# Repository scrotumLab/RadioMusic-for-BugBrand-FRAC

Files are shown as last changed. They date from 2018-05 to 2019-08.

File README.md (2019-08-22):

# RadioMusic v3.2 for BugBrand Modular System
With the permission of Tom Whitwell (Music Thing Modular), creator of [the original Radio Music module](https://github.com/TomWhitwell/RadioMusic), Scrotum Lab made different versions of the project compatible with the BugBrand Modular System in FRAC format.

This project was only made possible because Tom Whitwell licensed all hardware and software design as Creative Commons: [CC-BY-SA: Attribution / ShareAlike](https://creativecommons.org/licenses/by-sa/3.0/), allowing people to learn and share knowledge.  
Without him or other great creators like Emilie Gillet, I would have been incapable of doing the Scrotum Lab adaptations for the BugBrand system.

Here you will find:
- The latest version of the schematics and board files in Diptrace format.
- The Arduino code which was changed to allow mixing & attenuation to the circuit and works on v3.x versions of the Scrotum Lab module (not the earlier versions which still use the original Music Thing Modular code). 
- The frontpanel design as GERBER file (frontpanels in the BugBrand system are made of PCB material).
- The settings.txt file to put on your SD Card.

As the main purpose of the Scrotum Lab Radio Music was to be used as a sample player, the main markings on the front panel were changed: "Station" became "Sample Select" / "Start" became "Pitch" / "Reset" became "Trig".

Instead of 3.5mm plugs, banana plugs are used like the ones found on the BugBrand system.<br>

2 x CV inputs were added to mix/attenuate the incoming signal at "Sample Select" and "Pitch" inputs.<br> 
These CV inputs now accept bipolar signal -5V/+5V or unipolar +10V.<br> 

Mostly all through hole components were replaced by SMD components (0805).<br> 

Scrotum-Lab-Radio-Music-v3 1

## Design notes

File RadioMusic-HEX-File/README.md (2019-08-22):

Compiled version of the Arduino code for Scrotum Lab's Radio Music v3.x.

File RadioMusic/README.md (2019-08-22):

Here you will find the code which was changed to allow mixing & attenuation to the circuit and works on v3.x versions of the Scrotum Lab module (not the earlier versions which still use the original Music Thing Modular code).

The [original code](https://github.com/TomWhitwell/RadioMusic) was made by Tom Whitwell (Music Thing Modular) under Creative Commons license: [CC-BY-SA: Attribution / ShareAlike](https://creativecommons.org/licenses/by-sa/3.0/).

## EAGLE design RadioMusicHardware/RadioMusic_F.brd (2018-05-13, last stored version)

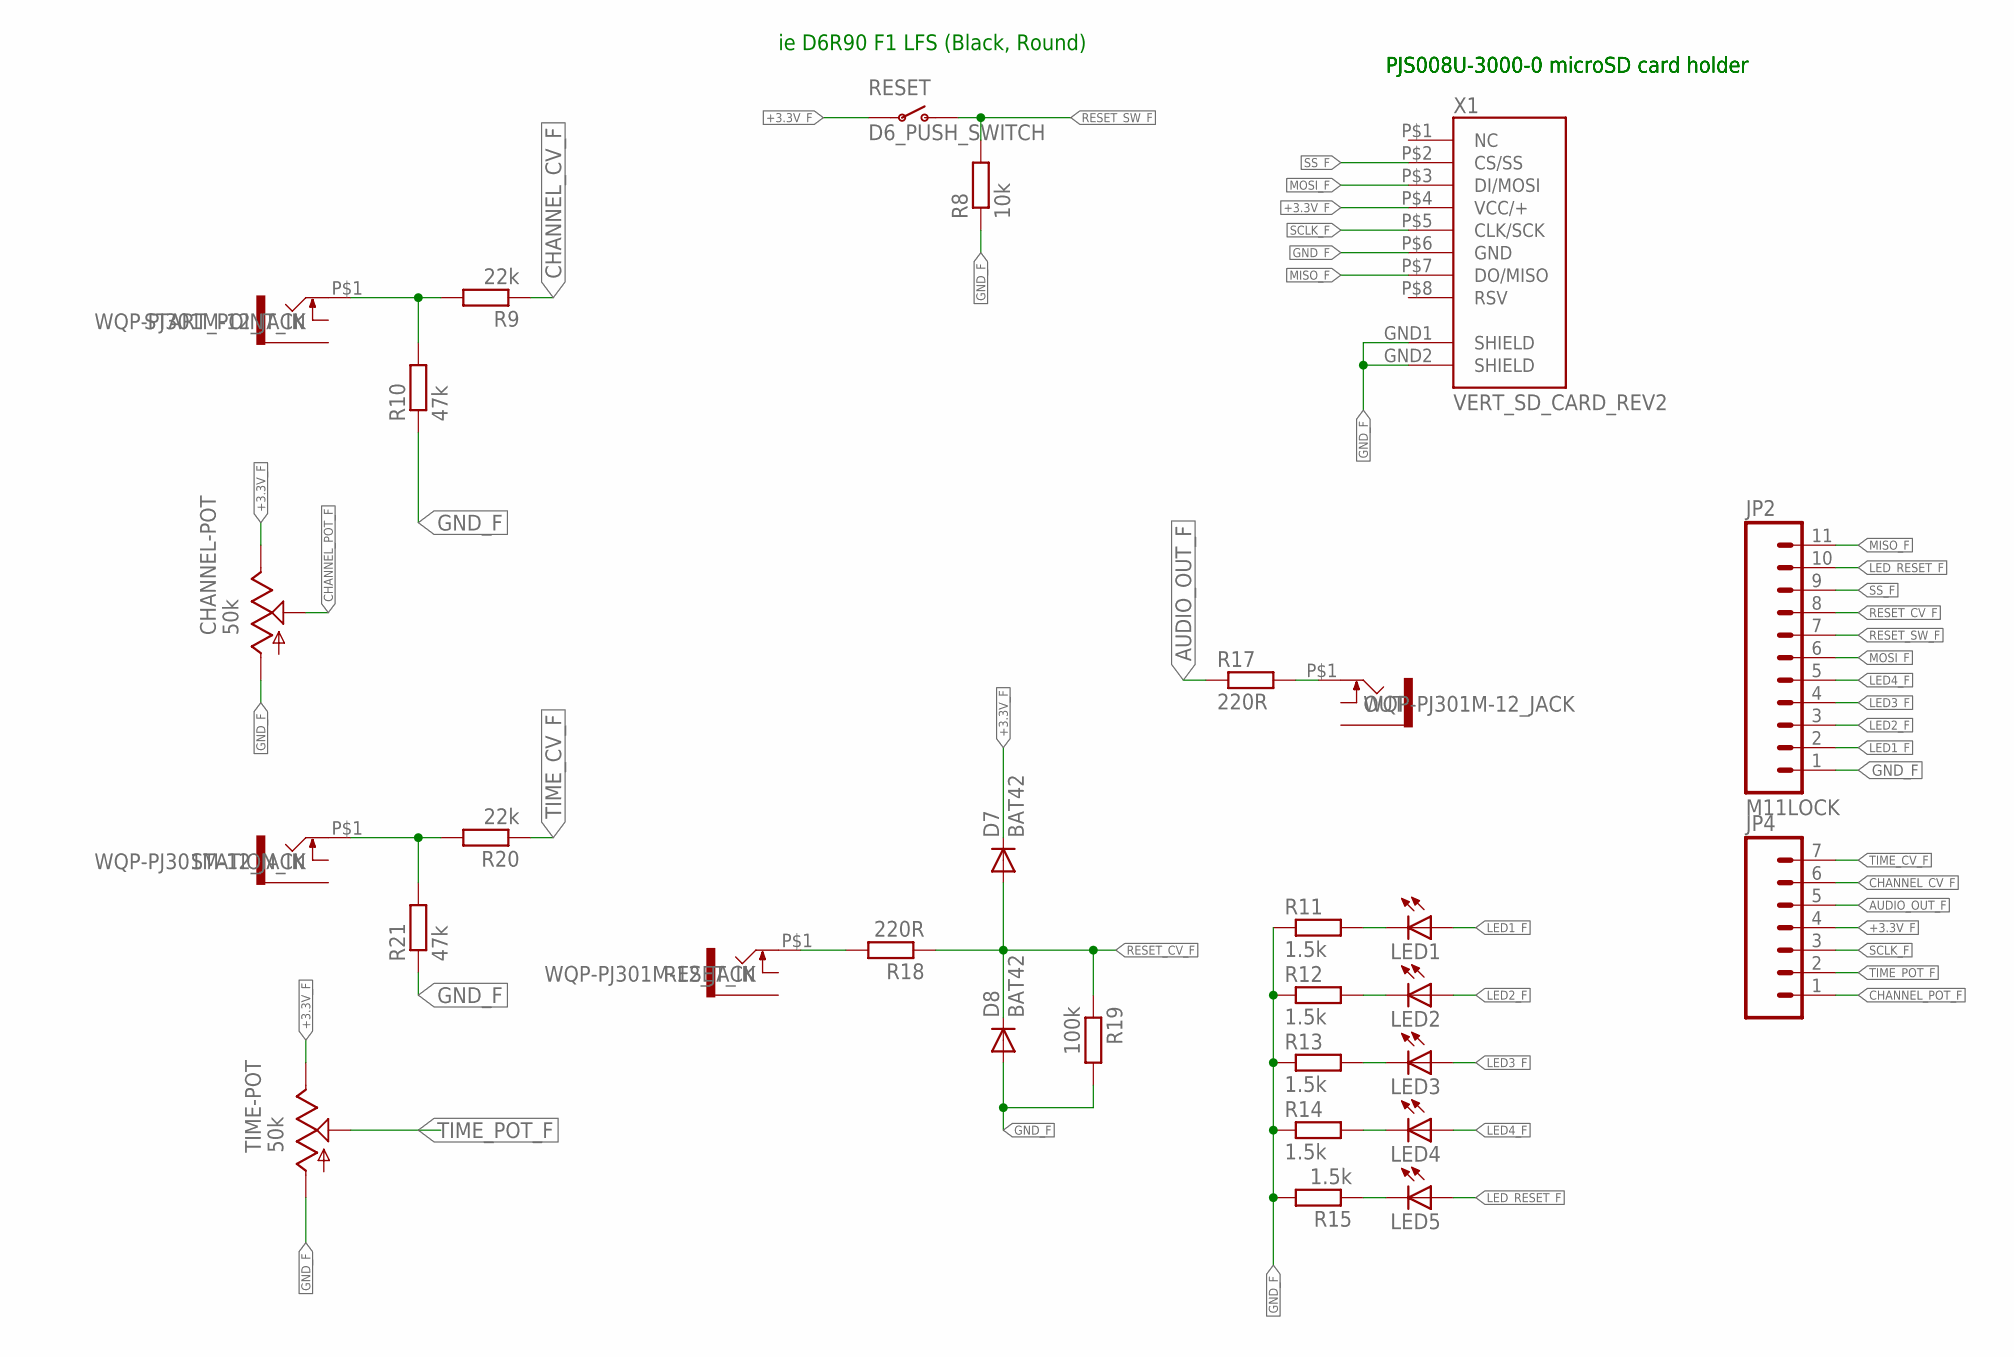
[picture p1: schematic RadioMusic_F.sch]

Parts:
CHANNEL-POT: 50k; EVUF
D7, D8: BAT42; DO34-7
JP2: M11LOCK; 1X11_LOCK
JP4: M07LOCK; 1X07_LOCK
LED1, LED2, LED3, LED4, LED5: LED3MM
OUT: WQP-PJ301M-12_JACK
R8: 10k; 0207/10
R9, R20: 22k; 0207/10
R10, R21: 47k; 0207/10
R11, R12, R13, R14, R15: 1.5k; 0207/10
R17, R18: 220R; 0207/10
R19: 100k; 0207/10
RESET: D6_PUSH_SWITCH; D6_BUTTON_RND
RESET_IN: WQP-PJ301M-12_JACK
START_POINT_IN: WQP-PJ301M-12_JACK
STATION_IN: WQP-PJ301M-12_JACK
TIME-POT: 50k; EVUF
X1: VERT_SD_CARD_REV2; VERT_MICROSD_REV2

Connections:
+3.3V_F: CHANNEL-POT.3 (E), D7.C, JP4.4, RESET.P$3, RESET.P$4, TIME-POT.3 (E), X1.P$4 (VCC/+)
AUDIO_OUT_F: JP4.5, R17.1
CHANNEL_CV_F: JP4.6, R9.1
CHANNEL_POT_F: CHANNEL-POT.2 (S), JP4.1
GND_F: CHANNEL-POT.1 (A), D8.A, JP2.1, R8.1, R10.1, R11.1, R12.1, R13.1, R14.1, R15.2, R19.2, R21.1, TIME-POT.1 (A), X1.GND1 (SHIELD), X1.GND2 (SHIELD), X1.P$6 (GND)
LED1_F: JP2.2, LED1.A
LED2_F: JP2.3, LED2.A
LED3_F: JP2.4, LED3.A
LED4_F: JP2.5, LED4.A
LED_RESET_F: JP2.10, LED5.A
MISO_F: JP2.11, X1.P$7 (DO/MISO)
MOSI_F: JP2.6, X1.P$3 (DI/MOSI)
unnamed: OUT.P$1, R17.2
unnamed: R9.2, R10.2, START_POINT_IN.P$1
unnamed: R18.2, RESET_IN.P$1
unnamed: LED1.K (C), R11.2
unnamed: LED2.K (C), R12.2
unnamed: LED3.K (C), R13.2
unnamed: LED4.K (C), R14.2
unnamed: LED5.K (C), R15.1
RESET_CV_F: D7.A, D8.C, JP2.8, R18.1, R19.1
RESET_SW_F: JP2.7, R8.2, RESET.P$1 (O), RESET.P$2 (O)
SCLK_F: JP4.3, X1.P$5 (CLK/SCK)
SS_F: JP2.9, X1.P$2 (CS/SS)
TEMP: R20.2, R21.2, STATION_IN.P$1
TIME_CV_F: JP4.7, R20.1
TIME_POT_F: JP4.2, TIME-POT.2 (S)

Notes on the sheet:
ie D6R90 F1 LFS (Black, Round)
PJS008U-3000-0 microSD card holder

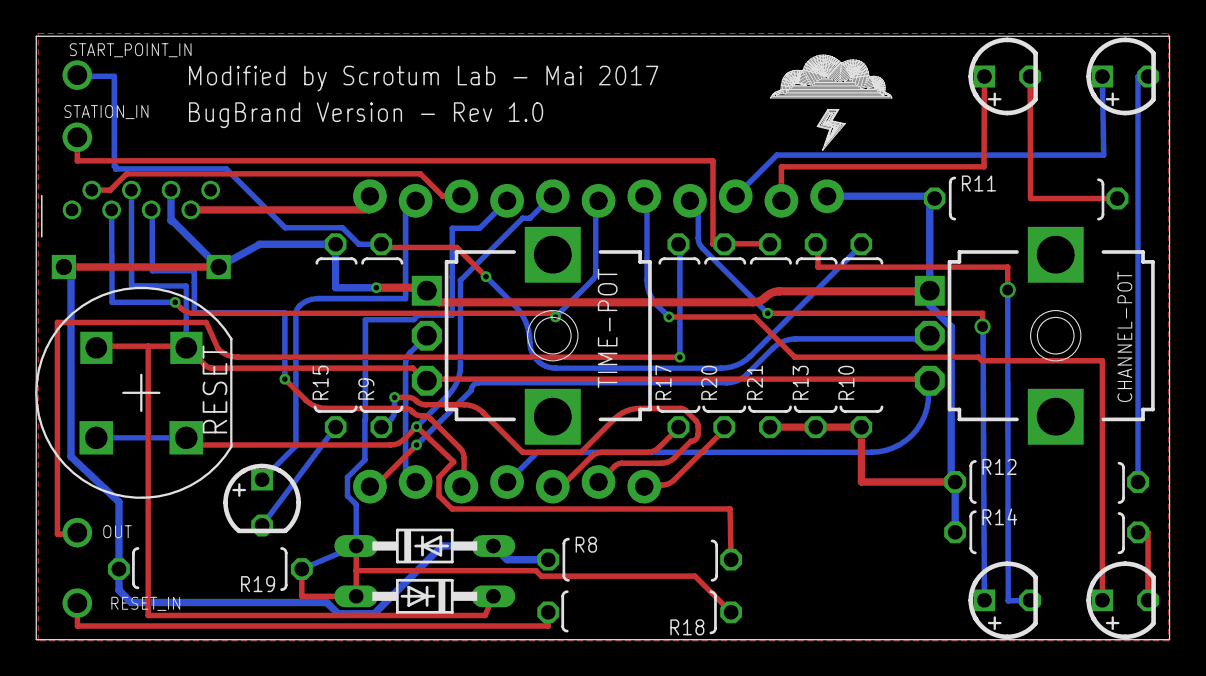
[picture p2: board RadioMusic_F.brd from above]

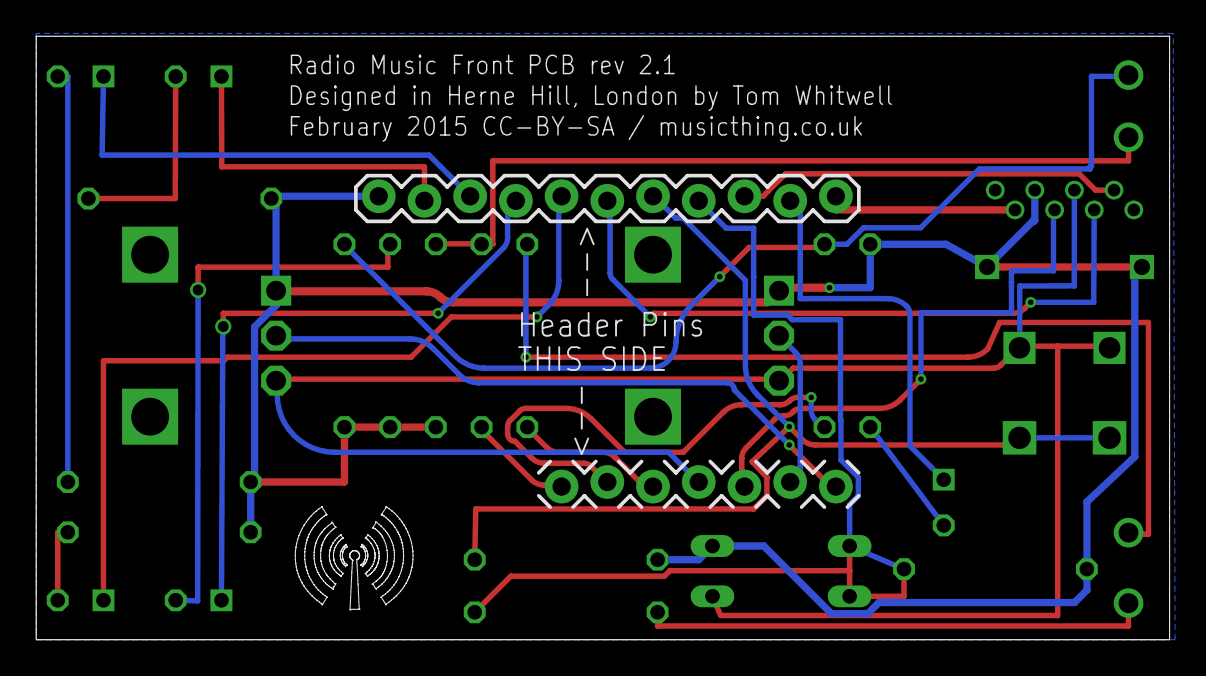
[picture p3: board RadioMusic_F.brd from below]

Board: 4 copper layers, 63.0 x 33.5 mm, 30 parts (2 on the bottom side), 27 nets.

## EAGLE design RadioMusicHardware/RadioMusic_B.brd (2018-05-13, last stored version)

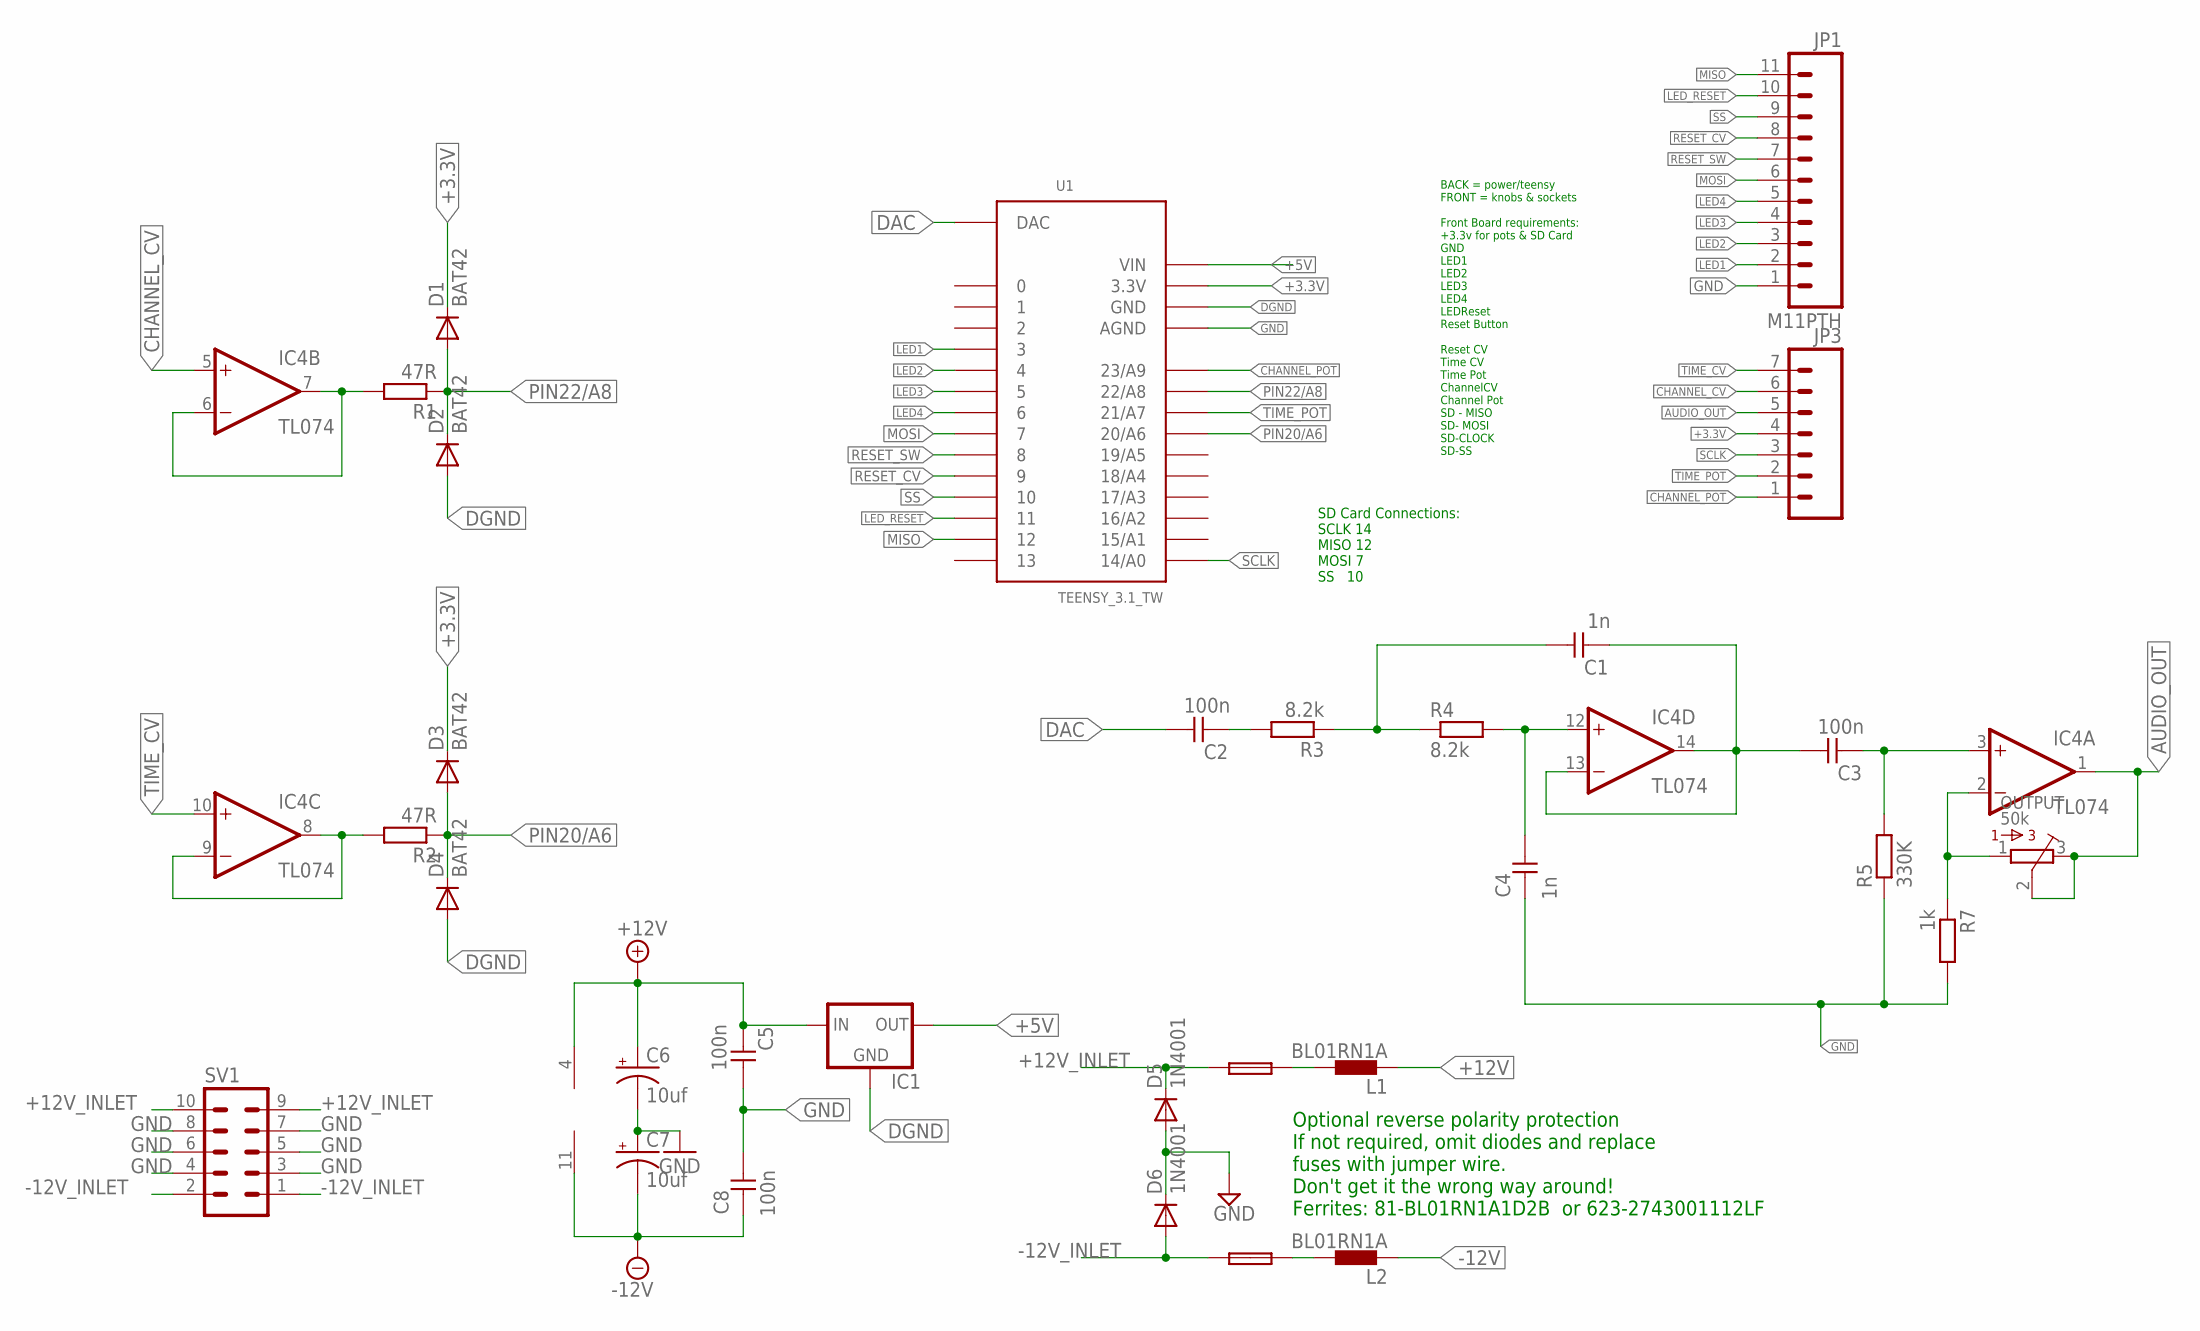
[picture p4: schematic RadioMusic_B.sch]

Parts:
C1, C4: 1n; C050-024X044
C2, C3: 100n; C050-025X075
C5, C8: 100n; C050-024X044
C6, C7: 10uf; CPOL-RADIAL-10UF-25V
D1, D2, D3, D4: BAT42; DO34-7
D5, D6: 1N4001; DO41-10
F1, F2: FUSE; C050H075X075
IC1: 78LXX
IC4: TL074; DIL14
JP1: M11PTH; 1X11
JP3: M07; 1X07
L1, L2: BL01RN1A
OUTPUT: 50k; 3362P
R1, R2: 47R; 0207/10
R3, R4: 8.2k; 0207/10
R5: 330K; 0207/10
R7: 1k; 0207/10
SV1: 10_PIN_HEADER; MA05-2
U1: TEENSY_3.1_TW

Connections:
+3.3V: D1.C, D3.C, JP3.4, U1.3.3V
+5V: IC1.OUT, U1.VIN
+12V: C5.2, C6.1 (+), IC1.IN, IC4.4 (V+), L1.1
+12V_INLET: D5.C, F1.1, SV1.9, SV1.10
-12V: C7.2 (-), C8.2, IC4.11 (V-), L2.1
-12V_INLET: D6.A, F2.1, SV1.1, SV1.2
AUDIO_OUT: IC4.1 (OUT), JP3.5, OUTPUT.2, OUTPUT.3
CHANNEL_CV: IC4.5 (+IN), JP3.6
CHANNEL_POT: JP3.1, U1.23/A9
DAC: C2.1, U1.DAC
DGND: D2.A, D4.A, IC1.GND, U1.GND
GND: C4.2, C5.1, C6.2 (-), C7.1 (+), C8.1, D5.A, D6.C, JP1.1, R5.1, R7.2, SV1.3, SV1.4, SV1.5, SV1.6, SV1.7, SV1.8, U1.AGND
LED1: JP1.2, U1.3
LED2: JP1.3, U1.4
LED3: JP1.4, U1.5
LED4: JP1.5, U1.6
LED_RESET: JP1.10, U1.11
MISO: JP1.11, U1.12
MOSI: JP1.6, U1.7
unnamed: IC4.8 (OUT), IC4.9 (-IN), R2.2
unnamed: C4.1, IC4.12 (+IN), R4.2
unnamed: IC4.6 (-IN), IC4.7 (OUT), R1.2
unnamed: C1.1, R3.1, R4.1
unnamed: C1.2, C3.1, IC4.13 (-IN), IC4.14 (OUT)
unnamed: C3.2, IC4.3 (+IN), R5.2
unnamed: IC4.2 (-IN), OUTPUT.1, R7.1
unnamed: C2.2, R3.2
unnamed: F1.2, L1.2
unnamed: F2.2, L2.2
PIN20/A6: D3.A, D4.C, R2.1, U1.20/A6
PIN22/A8: D1.A, D2.C, R1.1, U1.22/A8
RESET_CV: JP1.8, U1.9
RESET_SW: JP1.7, U1.8
SCLK: JP3.3, U1.14/A0
SS: JP1.9, U1.10
TIME_CV: IC4.10 (+IN), JP3.7
TIME_POT: JP3.2, U1.21/A7

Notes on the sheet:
Optional reverse polarity protection If not required, omit diodes and replace fuses with jumper wire. Don't get it the wrong way around! Ferrites: 81-BL01RN1A1D2B or 623-2743001112LF
SD Card Connections: SCLK 14 MISO 12 MOSI 7 SS 10
BACK = power/teensy FRONT = knobs & sockets Front Board requirements: +3.3v for pots & SD Card GND LED1 LED2 LED3 LED4 LEDReset Reset Button Reset CV Time CV Time Pot ChannelCV Channel Pot SD - MISO SD- MOSI SD-CLOCK SD-SS

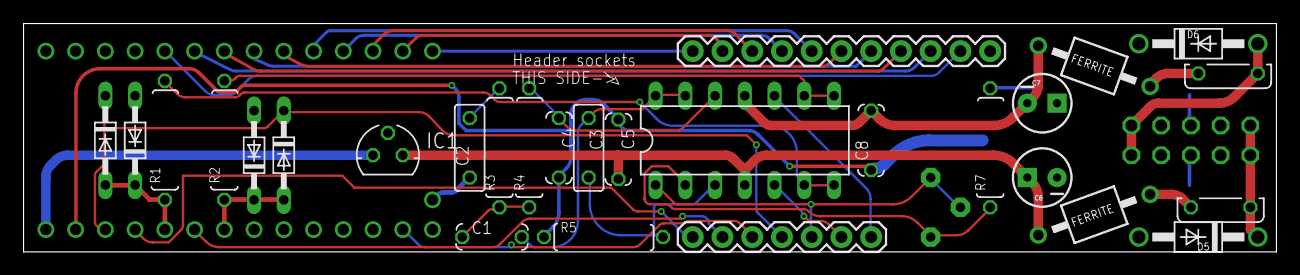
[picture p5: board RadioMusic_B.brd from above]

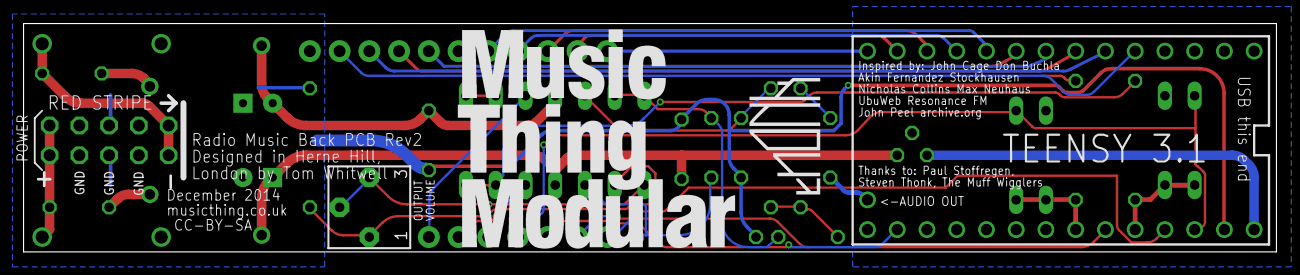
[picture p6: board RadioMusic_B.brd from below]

Board: 4 copper layers, 107.0 x 19.5 mm, 33 parts (5 on the bottom side), 37 nets.

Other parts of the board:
U$2: THONK_1CM_SCREENPRINT
U$4: MTM_2CM

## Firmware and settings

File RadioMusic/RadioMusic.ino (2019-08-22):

/*
 RADIO MUSIC
 https://github.com/TomWhitwell/RadioMusic

 Audio out: Onboard DAC, teensy3.1 pin A14/DAC
 
 Bank Button: 2
 Bank LEDs 3,4,5,6
 Reset Button: 8  
 Reset LED 11 
 Reset CV input: 9 
 
 Channel Pot: A9 // SLab inactive now - CHANNEL means PITCH
 Channel CV: A8  (original = A6)
 Time Pot: A7  // Slab inactive now - TIME means SAMPLE-SELECT
 Time CV: A6  (original = A8)
 
 SD Card Connections: 
 SCLK 14
 MISO 12
 MOSI 7 
 SS   10 
 
 NB: Compile using modified versions of: 
 SD.cpp (found in the main Arduino package) 
 play_sd_raw.cpp  - In Teensy Audio Library 
 play_sc_raw.h    - In Teensy Audio Library 
 
 from:https://github.com/TomWhitwell/RadioMusic/tree/master/Collateral/Edited%20teensy%20files

 Additions and changes:
 2016 by Jouni Stenroos - jouni.stenroos@iki.fi 
 - New bank change mode
 - Removing 330 file limit
 - Improving reset
 - File sorting
 - Audio crossfade
 - Some refactoring and organization of code.

October 2018 by Scrotum Lab
- All changes affect pot - Now pot is mixed / att with CV IN. It does not go directly anymore to DAC.
- Main changes: 
-- pot commented
-- cv + pot combi changed
-- changed also txt file on card - Variables are now external - easier to experiment with note range and also set to BugBrand (-5v/+5v) or Eurorack mode (0v/+5v)
 
 */
#include <EEPROM.h>
#include <SPI.h>
#include <SD.h>
#include <Wire.h>
#include "RadioMusic.h"
#include "AudioSystemHelpers.h"
#include "Settings.h"
#include "LedControl.h"
#include "FileScanner.h"
#include "AudioEngine.h"
#include "Interface.h"
#include "PlayState.h"

#ifdef DEBUG
#define D(x) x
#else
#define D(x)
#endif

// Press reset button to reboot
//#define RESET_TO_REBOOT
#define ENGINE_TEST

#define EEPROM_BANK_SAVE_ADDRESS 0

#define FLASHTIME 	10  	// How long do LEDs flash for?
#define SHOWFREQ 	250 	// how many millis between serial Debug updates

#define peakFPS 30   //  FRAMERATE FOR PEAK METER

#define SD_CARD_CHECK_DELAY 20

// //////////
// TIMERS
// //////////

elapsedMillis showDisplay;
elapsedMillis resetLedTimer = 0;
elapsedMillis ledFlashTimer = 0;

elapsedMillis meterDisplayDelayTimer; // Counter to hide MeterDisplay after bank change
elapsedMillis peakDisplayTimer; // COUNTER FOR PEAK METER FRAMERATE


int prevBankTimer = 0;
boolean flashLeds = false;
boolean bankChangeMode = false;
File settingsFile;

Settings settings("SETTINGS.TXT");
LedControl ledControl;
FileScanner fileScanner;
AudioEngine audioEngine;
Interface interface;
PlayState playState;

int NO_FILES = 0;
uint8_t noFilesLedIndex = 0;

uint8_t rebootCounter = 0;

void setup() {
#ifdef DEBUG_STARTUP
	while( !Serial );
	Serial.println("Starting");
#endif // DEBUG_STARTUP

	ledControl.init();
	ledControl.single(playState.bank);

	// SD CARD SETTINGS FOR AUDIO SHIELD
	SPI.setMOSI(7);
	SPI.setSCK(14);

	boolean hasSD = openSDCard();
	if(!hasSD) {
		Serial.println("Rebooting");
		reBoot(0);
	}

	settings.init(hasSD);

	File root = SD.open("/");
	fileScanner.scan(&root, settings);

	getSavedBankPosition();

	audioEngine.init(settings);

	int numFiles = 0;
	for(int i=0;i<=fileScanner.lastBankIndex;i++) {
		numFiles += fileScanner.numFilesInBank[i];
	}
	D(Serial.print("File Count ");Serial.println(numFiles););

	if(numFiles == 0) {
		NO_FILES = 1;
		D(Serial.println("No files"););
		ledFlashTimer = 0;
	} else if(fileScanner.numFilesInBank[playState.bank] == 0) {
		D(Serial.println("Empty bank"););
		while(fileScanner.numFilesInBank[playState.bank] == 0) {
			playState.bank++;
			if(playState.bank == fileScanner.lastBankIndex) {
				playState.bank = 0;
			}
		}
		D(Serial.print("Set bank to ");Serial.println(playState.bank););
	}

	interface.init(fileScanner.fileInfos[playState.bank][0].size, fileScanner.numFilesInBank[playState.bank], settings, &playState);

	D(Serial.println("--READY--"););
}

void getSavedBankPosition() {
	// CHECK  FOR SAVED BANK POSITION
	int a = 0;
	a = EEPROM.read(EEPROM_BANK_SAVE_ADDRESS);
	if (a >= 0 && a <= fileScanner.lastBankIndex) {
		D(
			Serial.print("Using bank from EEPROM ");
			Serial.print(a);
			Serial.print(" . Active banks ");
			Serial.println(fileScanner.lastBankIndex);

		);
		playState.bank = a;
		playState.channelChanged = true;
	} else {
		EEPROM.write(EEPROM_BANK_SAVE_ADDRESS, 0);
	};
}

boolean openSDCard() {
	if (!(SD.begin(SS))) {

		Serial.println("No SD.");
		while (!(SD.begin(SS))) {
			ledControl.single(15);
			delay(SD_CARD_CHECK_DELAY);
			ledControl.single(rebootCounter % 4);
			delay(SD_CARD_CHECK_DELAY);
			rebootCounter++;
			Serial.print("Crash Countdown ");
			Serial.println(rebootCounter);
			if (rebootCounter > 4) {
				return false;
			}
		}
	}
	return true;
}

void loop() {

	#ifdef CHECK_CPU
	checkCPU();
//	audioEngine.measure();
	#endif

	if(NO_FILES) {
		// TODO : Flash the lights to show there are no files
		if(ledFlashTimer > 100) {
			ledControl.single(noFilesLedIndex);
			noFilesLedIndex++;
			noFilesLedIndex %= 4;
			ledFlashTimer = 0;
			rebootCounter ++;
			// Wait 3 seconds and reboot
			if(rebootCounter == 30) {
				reBoot(0);
			}
		}
		return;
	}

	updateInterfaceAndDisplay();

	audioEngine.update();

	if(audioEngine.error) {
		// Too many read errors, reboot
		Serial.println("Audio Engine errors. Reboot");
		reBoot(0);
	}

	if (playState.channelChanged) {
		D(
		Serial.print("RM: Going to next channel : ");
		if(playState.channelChanged) Serial.print("RM: Channel Changed. ");
		Serial.println("");
		);

		playState.currentChannel = playState.nextChannel;

		AudioFileInfo* currentFileInfo = &fileScanner.fileInfos[playState.bank][playState.nextChannel];

		audioEngine.changeTo(currentFileInfo, interface.start);
		playState.channelChanged = false;

		resetLedTimer = 0;

	}

}

void updateInterfaceAndDisplay() {

	uint16_t changes = checkInterface();
	updateDisplay(changes);
}

void updateDisplay(uint16_t changes) {
	if (showDisplay > SHOWFREQ) {
		showDisplay = 0;
	}
	if (bankChangeMode) {
		ledControl.showReset(1);// Reset led is on continuously when in bank change mode..
		if(!flashLeds) {
			ledControl.multi(playState.bank);
		}

	} else {
		ledControl.showReset(resetLedTimer < FLASHTIME); // flash reset LED
	}

	if (flashLeds) {
		if (ledFlashTimer < FLASHTIME * 4) {
			ledControl.multi(0x0F);
		} else if(ledFlashTimer < FLASHTIME * 8) {
			ledControl.multi(0);
		} else {
			ledFlashTimer = 0;
		}
	} else if (settings.showMeter && !bankChangeMode) {
		peakMeter();
	}
}

// INTERFACE //

uint16_t checkInterface() {

	uint16_t changes = interface.update();

	#ifdef RESET_TO_REBOOT
	if (changes & BUTTON_SHORT_PRESS) {
		reBoot(0);
	}
	#endif

	// BANK MODE HANDLING
	if((changes & BUTTON_LONG_PRESS) && !bankChangeMode) {
		D(Serial.println("Enter bank change mode"););
		bankChangeMode = true;
		nextBank();
//		ledFlashTimer = 0;
	} else if((changes & BUTTON_LONG_RELEASE) && bankChangeMode) {
		D(Serial.println("Exit bank change mode"););
		flashLeds = false;
		bankChangeMode = false;
	}

	if(changes & BUTTON_PULSE) {
//		flashLeds = false;
		if(bankChangeMode) {
			D(Serial.println("BUTTON PULSE"););
			nextBank();
		} else {
			D(Serial.println("Button Pulse but not in bank mode"););
		}

	}

	boolean resetTriggered = changes & RESET_TRIGGERED;

	bool skipToStartPoint = false;
	bool speedChange = false;

	if(settings.pitchMode) {

		if(resetTriggered) {
			skipToStartPoint = true;
		}

    // SLab
    if((changes & (ROOT_NOTE_CHANGED | ROOT_CV_CHANGED) ) || resetTriggered) {
      speedChange = true;
    }

	} else {

		if((changes & CHANGE_START_NOW) || resetTriggered) {
			skipToStartPoint = true;
		}
	}

	if(resetTriggered) {
		if((changes & CHANNEL_CHANGED) || playState.nextChannel != playState.currentChannel) {
			playState.channelChanged = true;
		} else {
			resetLedTimer = 0;
		}
	}

	if(speedChange) doSpeedChange();
	if(skipToStartPoint && !playState.channelChanged) {
		if(settings.pitchMode) {
			audioEngine.skipTo(0);
		} else {
			D(Serial.print("Skip to ");Serial.println(interface.start););
			audioEngine.skipTo(interface.start);
		}

	}

	return changes;
}

void doSpeedChange() {
	float speed = 1.0;

  // SLab note vars now in ext. text file on SD Card
  speed = interface.rootNote - settings.setRootNote;
  
	D(Serial.print("Root note ");Serial.println(interface.rootNote););
	speed = pow(2,speed / 12);

	audioEngine.setPlaybackSpeed(speed);
}

void nextBank() {

	if(fileScanner.lastBankIndex == 0) {
		D(Serial.println("Only 1 bank."););
		return;
	}
	playState.bank++;
	if (playState.bank > fileScanner.lastBankIndex) {
		playState.bank = 0;
	}
	if(fileScanner.numFilesInBank[playState.bank] == 0) {
		D(Serial.print("No file in bank ");Serial.println(playState.bank););
		nextBank();
	}

	if (playState.nextChannel >= fileScanner.numFilesInBank[playState.bank])
		playState.nextChannel = fileScanner.numFilesInBank[playState.bank] - 1;
	interface.setChannelCount(fileScanner.numFilesInBank[playState.bank]);
	playState.channelChanged = true;

	D(
		Serial.print("RM: Next Bank ");
		Serial.println(playState.bank);
	);

	meterDisplayDelayTimer = 0;
	EEPROM.write(EEPROM_BANK_SAVE_ADDRESS, playState.bank);
}

#ifdef ENGINE_TEST
boolean tested = false;
int testIndex = 0;

void engineTest() {

	if(!tested) {
		audioEngine.test(fileScanner.fileInfos[playState.bank][0],fileScanner.fileInfos[playState.bank][1]);
		tested = true;
	}

	uint8_t changes = interface.update();

	if(changes & BUTTON_SHORT_PRESS) {
		testIndex += 2;
		if(testIndex >= fileScanner.numFilesInBank[playState.bank]) {
			Serial.println("Back to start");
			testIndex = 0;
		}
		audioEngine.test(fileScanner.fileInfos[playState.bank][testIndex],fileScanner.fileInfos[playState.bank][testIndex+1]);
	}

	return;
}
#endif

void peakMeter() {
	if( (peakDisplayTimer < 50) || (meterDisplayDelayTimer < settings.meterHide) ) return;

	float peakReading = audioEngine.getPeak();
	int monoPeak = round(peakReading * 4);
	monoPeak = round(pow(2, monoPeak));
//	D(Serial.print("Peak ");Serial.print(peakReading,4);Serial.print(" ");Serial.println(monoPeak););
	ledControl.multi(monoPeak - 1);
	peakDisplayTimer = 0;
}

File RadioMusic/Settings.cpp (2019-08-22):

#include <SD.h>
#include "Settings.h"

#include "RadioMusic.h"

#ifdef DEBUG_SETTINGS
#define D(x) x
#else
#define D(x)
#endif

Settings::Settings(const char* filename) {
	_filename = filename;
}

void Settings::init(boolean hasSD) {

	if (!hasSD) {
		// Configure defaults
		copyDefaults();
	} else {
		if (SD.exists(_filename)) {
			read();
		} else {
			write();
			read();
		};
	}
}

void Settings::copyDefaults() {

}

void Settings::read() {

	D(Serial.println("Reading settings.txt"););

	char character;
	String settingName;
	String settingValue;
	settingsFile = SD.open("settings.txt");

	uint8_t NAME = 1;
	uint8_t VALUE = 2;
	uint8_t state = NAME;

	if (settingsFile) {
		while (settingsFile.available()) {
			character = settingsFile.read();
			if(state == NAME) {
				if(character == '=') {
					state = VALUE;
				} else {
					settingName = settingName + character;
				}
			} else if(state == VALUE) {
				if(character == '\n') {
					applySetting(settingName, settingValue);
					settingName = "";
					settingValue = "";
					state = NAME;
				} else {
					settingValue = settingValue + character;
				}
			}
		}
		if(settingName.length() > 0 && settingValue.length() > 0) {
			applySetting(settingName, settingValue);
		}
		// close the file:
		settingsFile.close();
	} else {
		// if the file didn't open, print an error:
		Serial.println("error opening settings.txt");
	}

#ifdef TEST_RADIO_MODE
	radioMode();
#endif

#ifdef TEST_DRUM_MODE
	drumMode();
#endif

	if(!loopMode) {
		if(pitchMode) {
			loopMode = LOOP_MODE_START_POINT;
		} else {
			loopMode = LOOP_MODE_RADIO;
		}
	}

	D(Serial.print("Loop mode ");Serial.println(loopMode););

	if(anyAudioFiles || pitchMode) {
		hardSwap = true;
	}
}

void Settings::drumMode() {
	crossfade=0;
	crossfadeTime=100;
	showMeter=1;
	meterHide=2000;
	chanCVImmediate=1;
	startCVImmediate=1;
	startCVDivider=1;
	looping=1;
	sort=1;
	pitchMode=1;
	hardSwap = true;
	anyAudioFiles = true;
	loopMode = LOOP_MODE_START_POINT;
}

void Settings::radioMode() {
	crossfade=1;
	crossfadeTime=100;
	showMeter=1;
	meterHide=2000;
	chanCVImmediate=1;
	startCVImmediate=0;
	startCVDivider=2;
	looping=1;
	sort=1;
	pitchMode=0;
	hardSwap = false;
	anyAudioFiles = false;
	loopMode = LOOP_MODE_RADIO;
}
/* Apply the value to the parameter by searching for the parameter name
 Using String.toInt(); for Integers
 toFloat(string); for Float
 toBoolean(string); for Boolean
 */
void Settings::applySetting(String settingName, String settingValue) {

	D(
	Serial.print(settingName);
	Serial.print(" -> ");
	Serial.println(settingValue);
	);

	if (settingName.equalsIgnoreCase("mute") || settingName.equalsIgnoreCase("crossfade")) {
		crossfade = toBoolean(settingValue);
	}

	if (settingName.equalsIgnoreCase("declick") || settingName.equalsIgnoreCase("crossfadeTime")) {
		crossfadeTime = settingValue.toInt();
	}

  // SLab note set in text file too
  if (settingName.equalsIgnoreCase("setLowNote")) {
    setLowNote = settingValue.toInt();
  }
  
  if (settingName.equalsIgnoreCase("setNoteRange")) {
    setNoteRange = settingValue.toInt();
  }
  
   if (settingName.equalsIgnoreCase("setRootNote")) {
    setRootNote = settingValue.toInt();
  }

	if (settingName.equalsIgnoreCase("showMeter")) {
		showMeter = toBoolean(settingValue);
	}

	if (settingName.equalsIgnoreCase("meterHide")) {
		meterHide = settingValue.toInt();
	}

	if (settingName.equalsIgnoreCase("chanCVImmediate")) {
		chanCVImmediate = toBoolean(settingValue);
	}

	if (settingName.equalsIgnoreCase("startCVImmediate")) {
		startCVImmediate = toBoolean(settingValue);
	}

	if (settingName.equalsIgnoreCase("startCVDivider")) {
		startCVDivider = settingValue.toInt();
	}

	if (settingName.equalsIgnoreCase("looping")) {
		looping = toBoolean(settingValue);
	}

	if (settingName.equalsIgnoreCase("sort")) {
		sort = toBoolean(settingValue);
	}

	if(settingName.equalsIgnoreCase("anyAudioFiles")) {
		anyAudioFiles = toBoolean(settingValue);
	}

	if(settingName.equalsIgnoreCase("pitchMode")) {
		pitchMode = toBoolean(settingValue);
	}

	if(settingName.equalsIgnoreCase("hardSwap")) {
		hardSwap = toBoolean(settingValue);
	}

	if(settingName.equalsIgnoreCase("noteRange")) {
		noteRange = settingValue.toInt();
		if(noteRange < 1) noteRange = 1;
		if(noteRange > 72) noteRange = 72;
	}

	if(settingName.equalsIgnoreCase("rootNote")) {
		rootNote = settingValue.toInt();
		if(rootNote < lowNote) rootNote = lowNote;
		if(rootNote > 96) rootNote = 96;
    
	}

	if(settingName.equalsIgnoreCase("loopMode")) {
		loopMode = settingValue.toInt();
	}

	if(settingName.equalsIgnoreCase("quantiseNoteCV") || settingName.equalsIgnoreCase("quantizeRootCV")) {
		quantiseRootCV = toBoolean(settingValue);
	}

}

// converting string to Float
float Settings::toFloat(String settingValue) {
	char floatbuf[settingValue.length()];
	settingValue.toCharArray(floatbuf, sizeof(floatbuf));
	float f = atof(floatbuf);
	return f;
}
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

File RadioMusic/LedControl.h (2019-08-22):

#ifndef LedControl_h
#define LedControl_h

/**
 * Chord Organ / Radio Music LED control
 *
 * 4 LEDs across the top and 1 reset LED.
 *
 */
#define LED0 6
#define LED1 5
#define LED2 4
#define LED3 3
#define RESET_LED 11 // Reset LED indicator

class LedControl {

	public:
		LedControl();
		void init();
		void single(int index);
		void multi(uint8_t bits);
		void bankAndSingle(int bank, int index);
		void flash();
		void showReset(boolean high);
	private:
		boolean flashingBank = false;
		elapsedMillis bankFlashTimer = 0;
		uint16_t bankLedFlashTimes[3] = {400,100,30};

};
#endif

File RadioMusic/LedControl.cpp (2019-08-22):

#include "Arduino.h"
#include "LedControl.h"

LedControl::LedControl() {

}

void LedControl::init() {
	pinMode(RESET_LED, OUTPUT);
    pinMode(LED0,OUTPUT);
    pinMode(LED1,OUTPUT);
    pinMode(LED2,OUTPUT);
    pinMode(LED3,OUTPUT);
}

// Set any combination of top row LEDS from the bottom 4 bits
// bit position is the opposite of light position
// e.g. if bottom 4 bits are 0001 the LEDs are * O O O
void LedControl::multi(uint8_t bits) {
    digitalWrite(LED3, HIGH && (bits & 1));
    digitalWrite(LED2, HIGH && (bits & 2));
    digitalWrite(LED1, HIGH && (bits & 4));
    digitalWrite(LED0, HIGH && (bits & 8));
}

// Set a single LED on the top row, others will be unlit
void LedControl::single(int index) {
    digitalWrite(LED3, HIGH && (index==0));
    digitalWrite(LED2, HIGH && (index==1));
    digitalWrite(LED1, HIGH && (index==2));
    digitalWrite(LED0, HIGH && (index==3));
}

void LedControl::showReset(boolean high) {
    digitalWrite(RESET_LED, high ? HIGH : LOW);
}

void LedControl::flash() {
    flashingBank = true;
    bankFlashTimer = 0;
}

// Set the bank and top row index.
// Different banks have different flashing rates
// Only supports 3 banks for now
void LedControl::bankAndSingle(int bank, int index) {
    // Flash waveform LEDs for custom waves
    if(bank > 0 && bank < 3) {
        if(bankFlashTimer >= bankLedFlashTimes[bank]) {
            bankFlashTimer = 0;
            flashingBank = !flashingBank;
            if(flashingBank) {
                single(index % 4);
            } else {
                single(15);
            }
        }
    } else {
    	single(index % 4);
    }
}

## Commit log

2018-05-13 test
    test
    [RadioMusic_B.brd, RadioMusic_B.sch, RadioMusic_F.brd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]
2018-05-13 Eagle files
    Rev 1.0
    [RadioMusic_B.brd, RadioMusic_B.sch, RadioMusic_F.brd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]
2019-08-22 Uploading Scrotum Lab PCB files
2019-08-22 Deleting original Music Thing PCB files
    [RadioMusic_B.brd]

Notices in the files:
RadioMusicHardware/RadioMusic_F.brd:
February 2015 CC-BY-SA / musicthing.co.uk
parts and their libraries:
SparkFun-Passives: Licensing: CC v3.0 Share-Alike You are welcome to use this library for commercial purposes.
